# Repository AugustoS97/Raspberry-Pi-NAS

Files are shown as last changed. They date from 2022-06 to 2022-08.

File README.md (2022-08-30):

# Raspberry Pi NAS Software

NAS (Network Attached Storage) basado en Rapsberry Pi con Open Media Vault impreso en 3D con HDD de 3,5" de Toshiba alimentado a 12V.
Este diseño pretende reaprovechar los Discos Duros Externos de 3,5" USB para ser usados como NAS en una carcasa que integra todo lo necesario.
Incorpora LEDs indicador de estado (LED verde) y de encendido (LED rojo), así como OLED para identificar la dirección IP, el espacio libre y los datos de consumo de RAM y CPU.

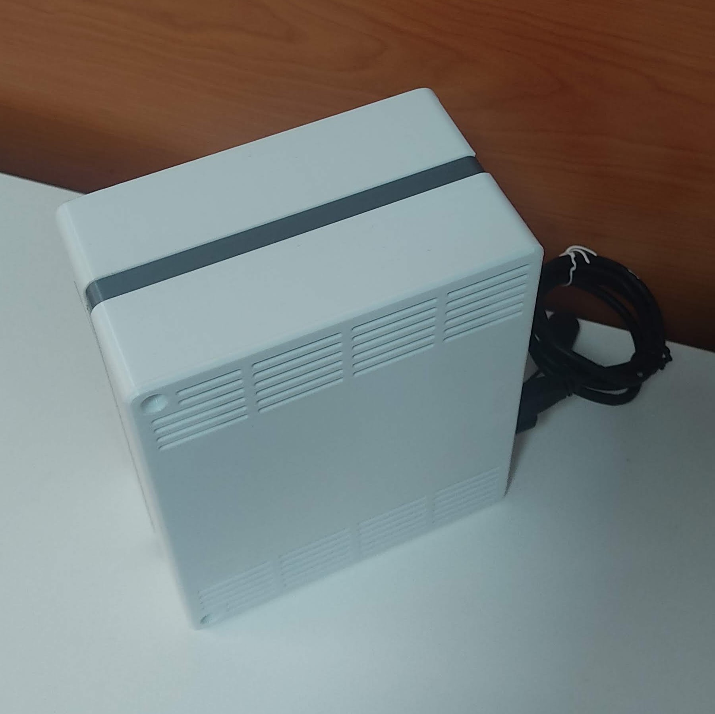
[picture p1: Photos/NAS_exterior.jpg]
NAS_exterior


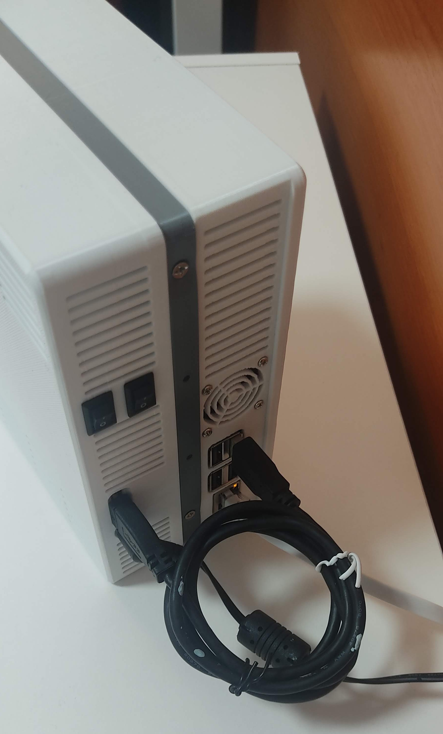
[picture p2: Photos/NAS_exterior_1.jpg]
NAS exterior 2


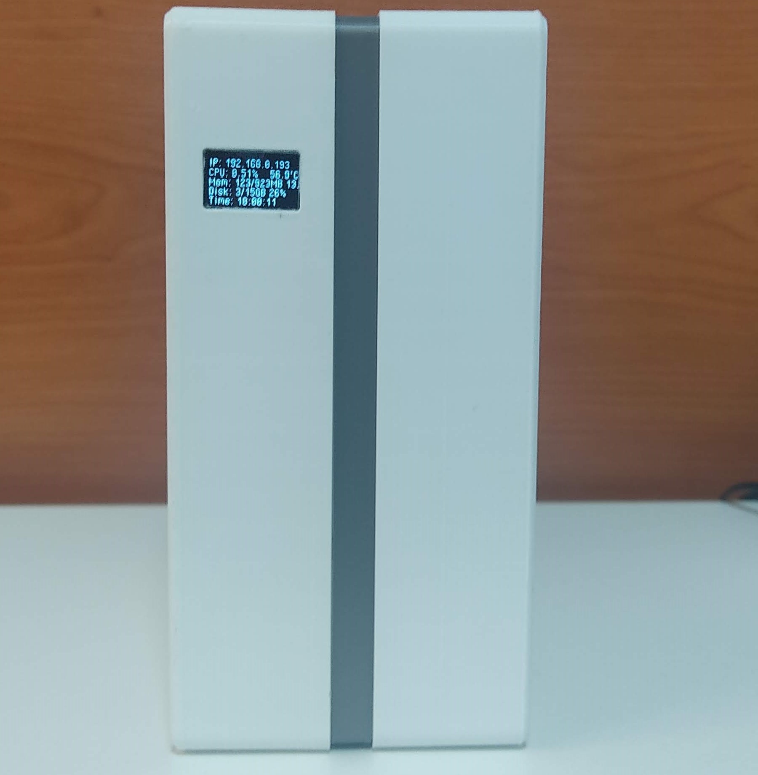
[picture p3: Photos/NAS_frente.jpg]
NAS frontal


## Lista de Materiales (BOM)

Para montar este sistema se precisa de lo siguiente:

### Elementos mecánicos

- 4 tornillos M3x15
- 12 tuercas M3.
- 10 tornillos M3x6 (para interior)
- 4 tornillos M2.5x6 (para RPi)
- 8 tornillos M3x10
- 2 tornillos M4x15
- 2 insertos M4
- Piezas impresas en PLA. Puedes localizarse en la carpeta 3D Model o en [Thingiverse](https://www.thingiverse.com/thing:5462342)
- Metacrilato de 3mm cortado para "cristal" de OLED.

### Electrónica

- Raspberry 3B+.
- Ventilador para Rapsberry Pi.
- Disco Duro 3,5" Toshiba o similar con placa de alimentación a 12V
- 2 Interruptores 8x15mm
- LED rojo
- LED amarillo
- 2 Resistencias 220 Ohm
- Regulador DC/DC StepDown MP2307 o LM2596
- Fusible 2A (Opcional para proteger alimentación de Raspberry)
- Placa para control del ventilador [PWM](https://github.com/AugustoS97/RPi-accessories/tree/main/PWM-TRANSISTOR-PCB) de diseño propio (opcional). En caso de querer controlar mediante PWM es necesario un transistor 2N2222, un diodo 1N4007 y una Resistencia de 1KOhm.
- Puede sustituirse la integración de los LEDs de estado, el fusible, el DC/DC y la placa para control PWM, empleando una [placa de expansión para RPi de diseño propio](https://github.com/AugustoS97/RPi-accessories/tree/main/LED-RPi-PCB).

### Esquema para el control PWM del ventilador

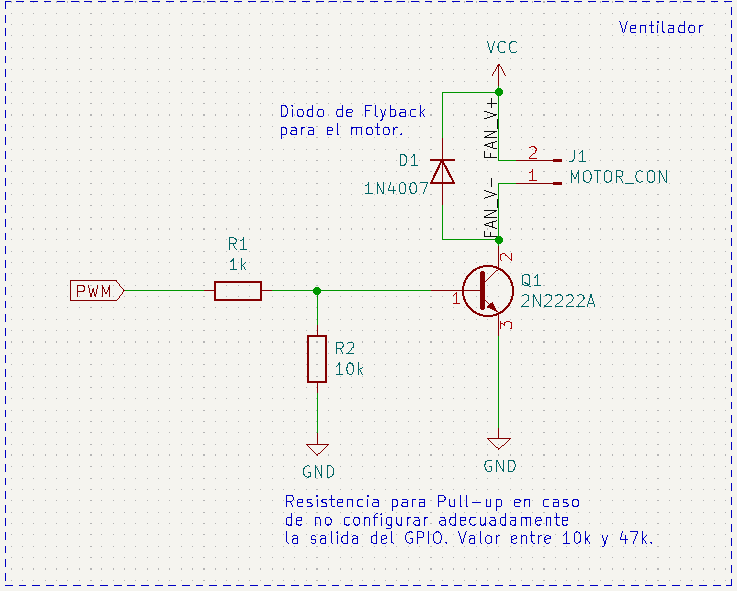
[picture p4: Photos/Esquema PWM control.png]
Esquema de control PWM


### Esquema para la Placa de expansión para RPi

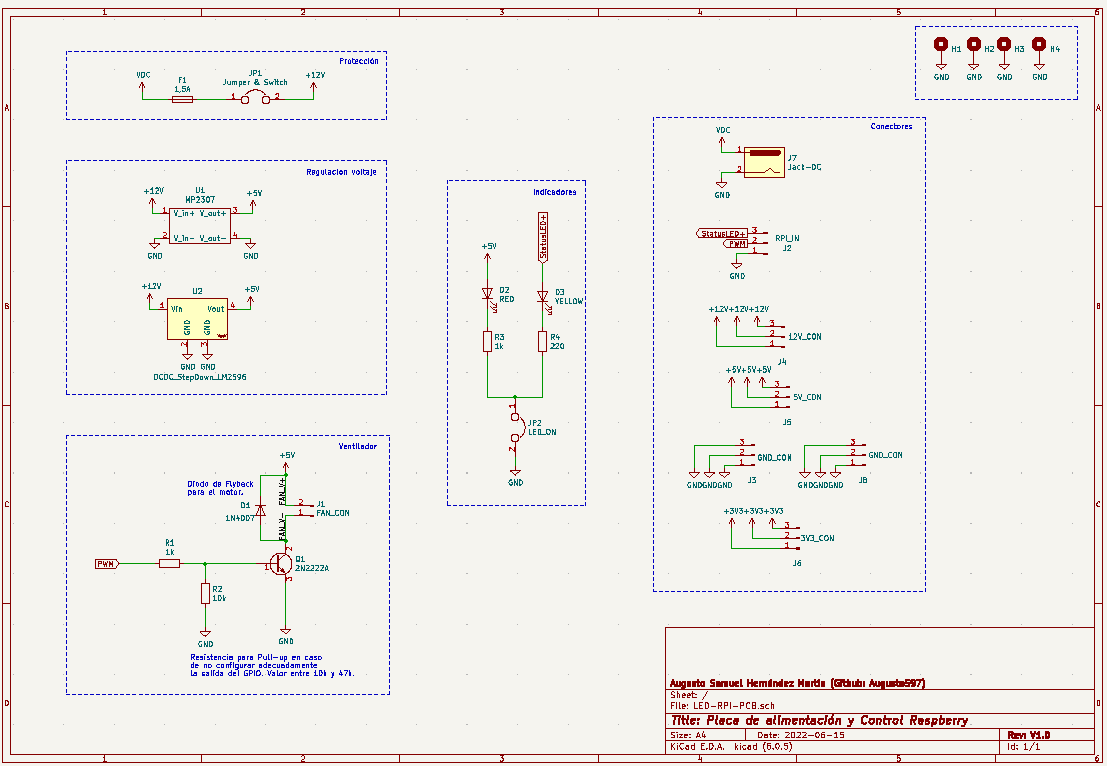
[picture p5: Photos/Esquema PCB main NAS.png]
Esquema placa RPi


## Instalar Open Media Vault

    $ sudo wget -O - https://github.com/OpenMediaVault-Plugin-Developers/installScript/raw/master/install | sudo bash $

## OLED STATISTIC

Servicio del sistema que lanza un script en python para mostar en un display OLED LCD los siguientes datos:

- Direccion IP
- Ocupacion del disco principal
- Consumo de RAM
- Temperatura
- Ocupacion del disco externo (en caso de emplearse como NAS).

## Requerimientos para el uso del Display OLED I2C

- Python3:
  
    $ sudo apt-get install python3-pip

	$ sudo pip3 install --upgrade setuptools

- Raspi blinka:
  
	$ wget https://raw.githubusercontent.com/adafruit/Raspberry-Pi-Installer-Scripts/master/raspi-blinka.py

	$ sudo python3 raspi-blinka.py

- Adafruit python shell:
  
	$ sudo pip3 install --upgrade adafruit-python-shell

- Adafruit SSD1306: 
  
	$ pip3 install adafruit-circuitpython-ssd1306

- Python PIL:
  
	$ sudo apt-get install python3-pil

## Carpeta con el contenido a copiar dentro de /home/pi

- Debe copiarse la carpeta shutdwon-monitor para permitir apagar meidante el boton conectado al GPIO-17 (pin BCM número 11).
- Debe copiarse la carpeta oled-statistic para ejecutar el script que muestra de forma continua la info en pantalla.

## Configuracion con Cron

- Abrir el configurador de cron con $ crontab -e $
- Escribir la configuracion con encendido retardado y volcado a un fichero de log: 

    $ @reboot sleep 2; /usr/bin/python3 /home/pi/oled-statistic/oled-statistic.py >> /home/pi/oled-statistic/oled-statistic.log

    $ @reboot sleep 10; /usr/bin/python3 /home/pi/shutdown-monitor/shutdown-monitor.py >> /home/pi/shutdown-monitor/shutdown-monitor.log
- Asegurarse de dar permiso de ejecucion a ambos scripts con 
    $ chmod 777 nombre.py

## Pines ocupados 

- Ventilador: GPIO 12 (PWM 3.3V). Se configura en el /boot/config.txt como 
  
    $ dtoverlay=gpio-fan,gpiopin=12,temp=60000
- LED Amarillo (Estatus LED): GPIO26. Se configura en el /boot/config.txt como 
  
    $ dtparam=act_led_gpio=26
- LED Rojo (Encendido LED): GPIO19

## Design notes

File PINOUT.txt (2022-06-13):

- Ventilador: GPIO 12 (PWM 3.3V)
- LED Amarillo (Estatus LED): GPIO26
- LED Rojo (Encendido LED): GPIO19
- Interruptor de encendido/apagado: GPIO3 y GND

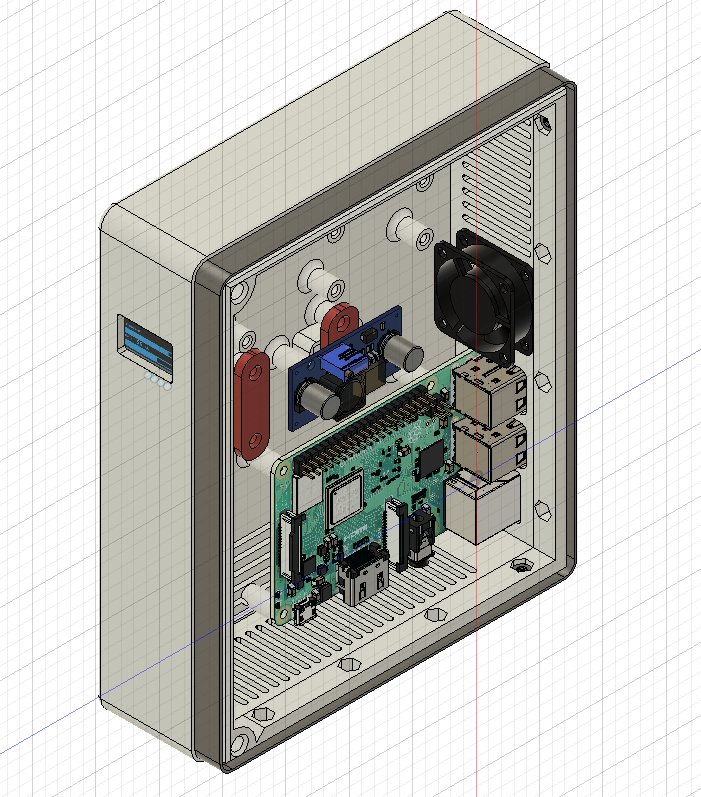
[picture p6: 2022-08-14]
3D Model/RENDER/Captura_2.png

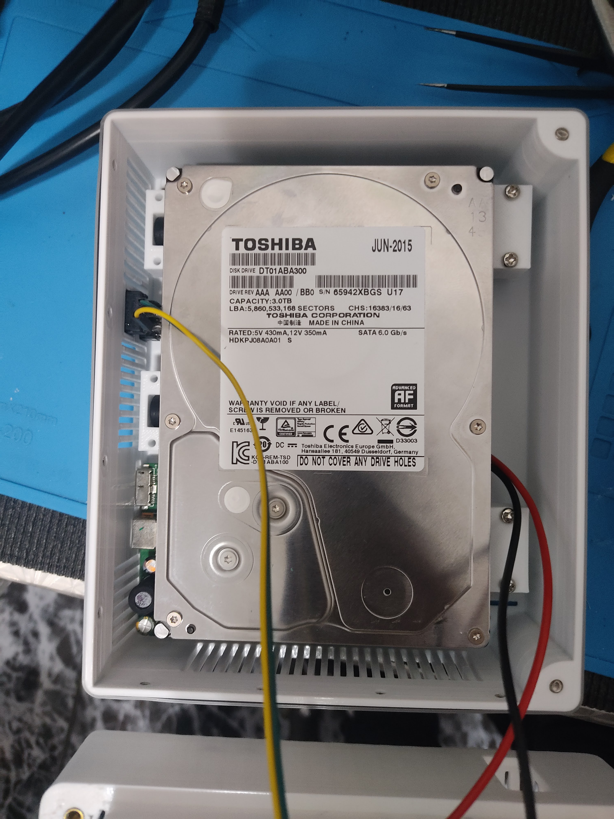
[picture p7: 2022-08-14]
Photos/NAS_HDD.jpg

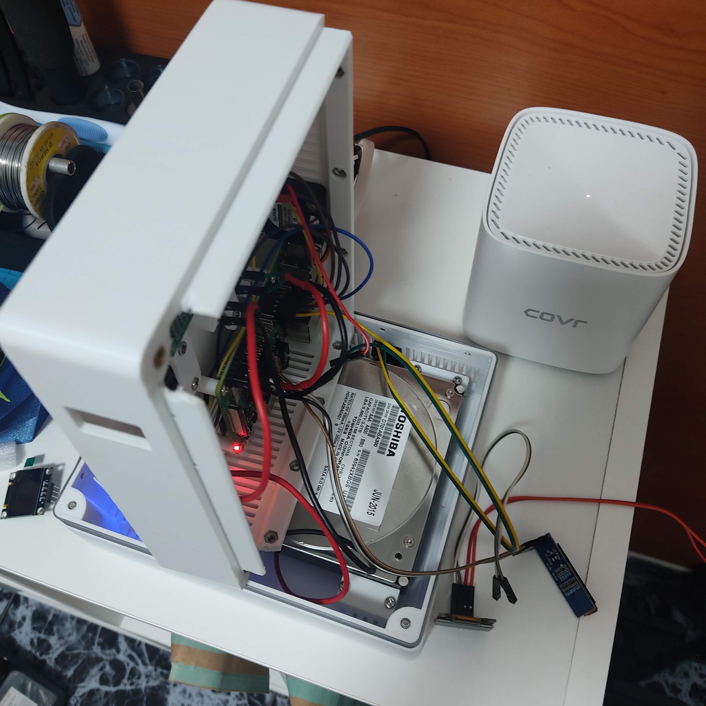
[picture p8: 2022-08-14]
Photos/NAS_interior_1.jpg

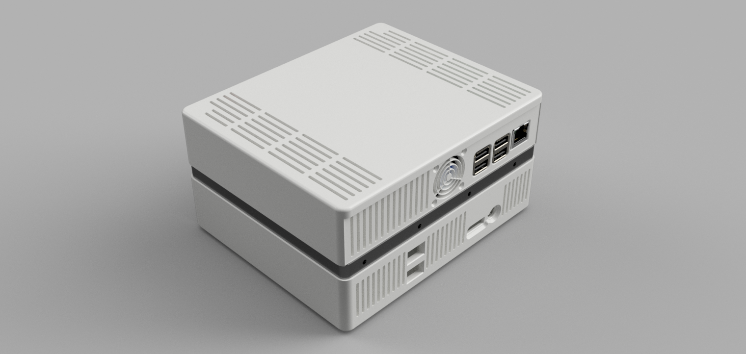
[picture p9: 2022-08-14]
3D Model/RENDER/NAS Servidor con OLED conectores.png

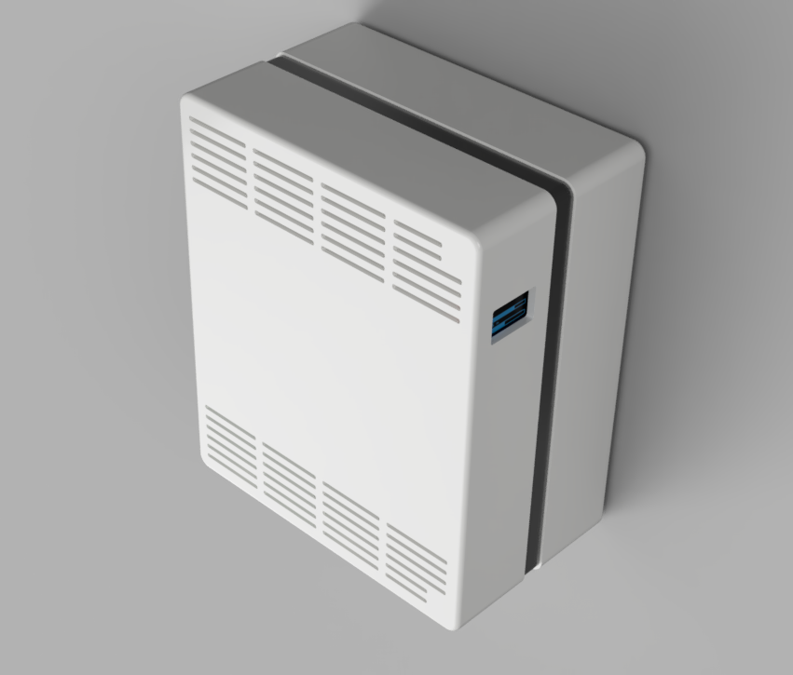
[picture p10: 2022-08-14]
3D Model/RENDER/NAS_Servidor_con_OLED_2022-Apr-21_08-00-08PM-000_CustomizedView2744614946_png.png

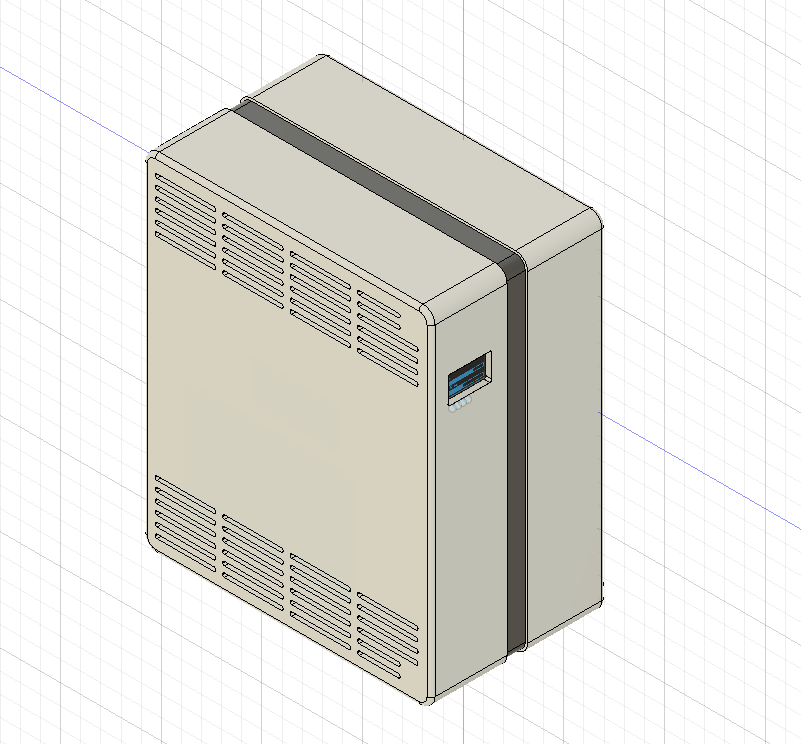
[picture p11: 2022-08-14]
3D Model/RENDER/Captura_1.png

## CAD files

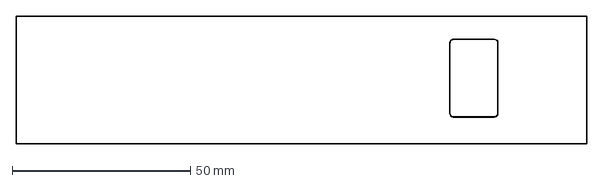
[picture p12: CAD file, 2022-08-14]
3D Model/DXF/Metacrilato 3mm pantalla OLED.dxf
160.0 x 35.8 mm

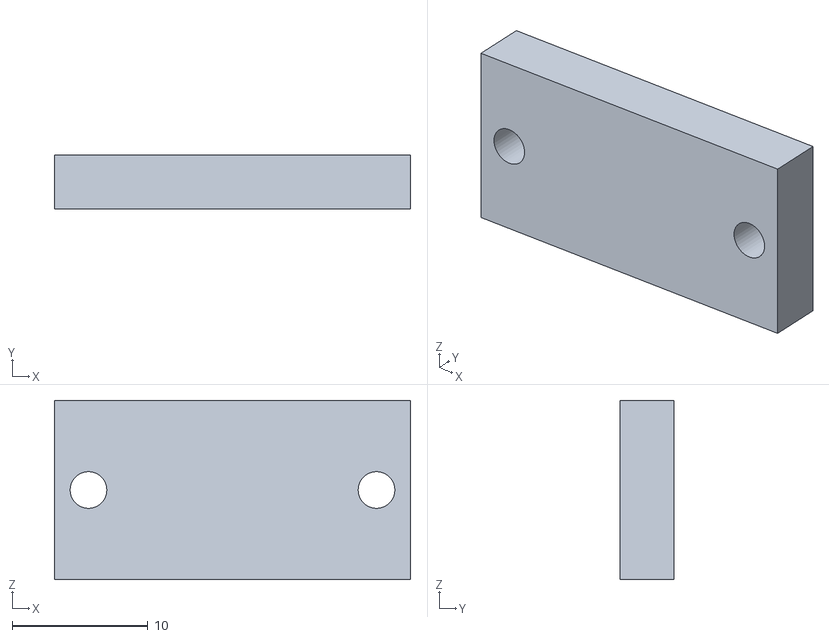
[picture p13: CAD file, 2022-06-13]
3D Model/STL/Soporte-HDD-Opuesto x2.stl
26.2 x 4.00 x 13.2

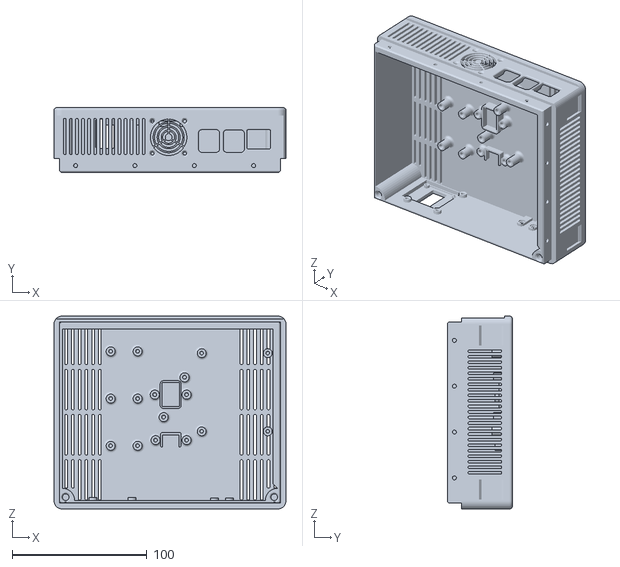
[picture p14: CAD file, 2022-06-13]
3D Model/STL/TapaDrcha.stl
172.0 x 48.0 x 143.0

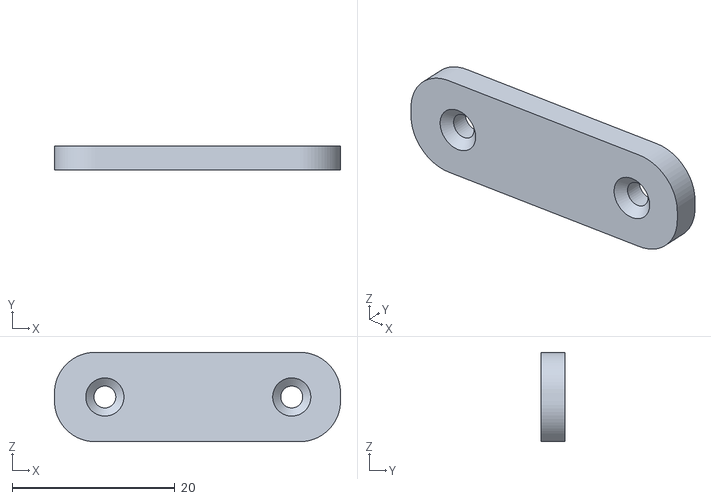
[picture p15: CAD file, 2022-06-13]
3D Model/STL/Soporte Fusible Mini.stl
35.2 x 3.00 x 11.0

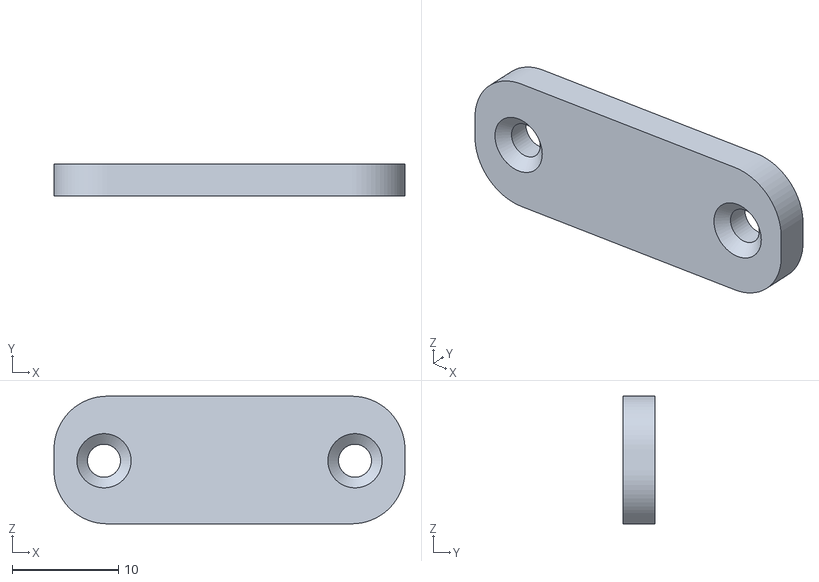
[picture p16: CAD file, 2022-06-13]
3D Model/STL/Soporte MP2307.stl
33.0 x 3.00 x 12.0

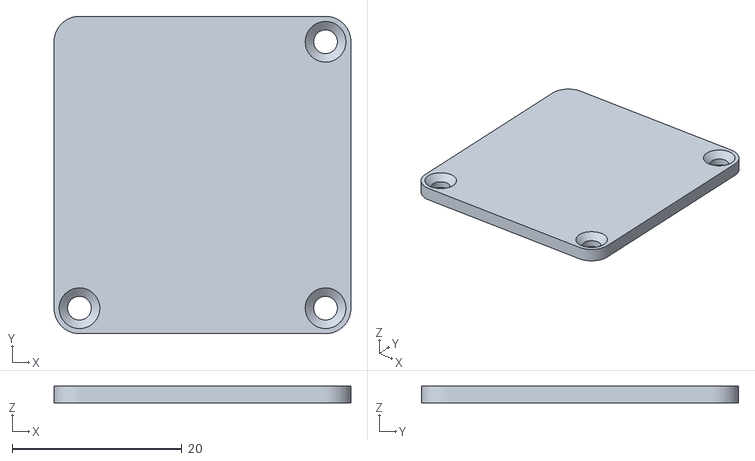
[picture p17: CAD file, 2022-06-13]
3D Model/STL/Soporte OLED.stl
35.0 x 37.4 x 2.00

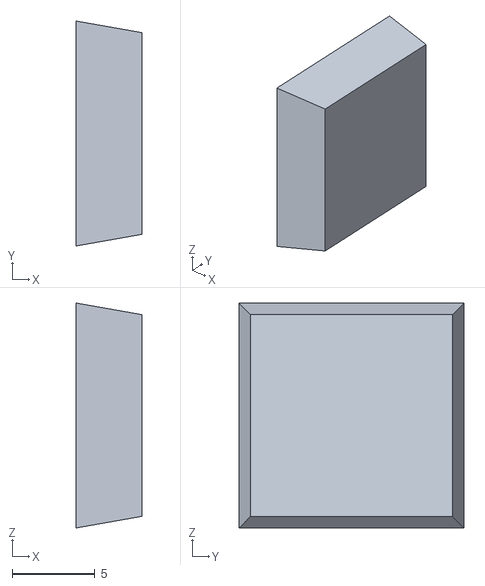
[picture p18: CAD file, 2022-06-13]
3D Model/STL/Taco Basex4.stl
4.00 x 13.6 x 13.6

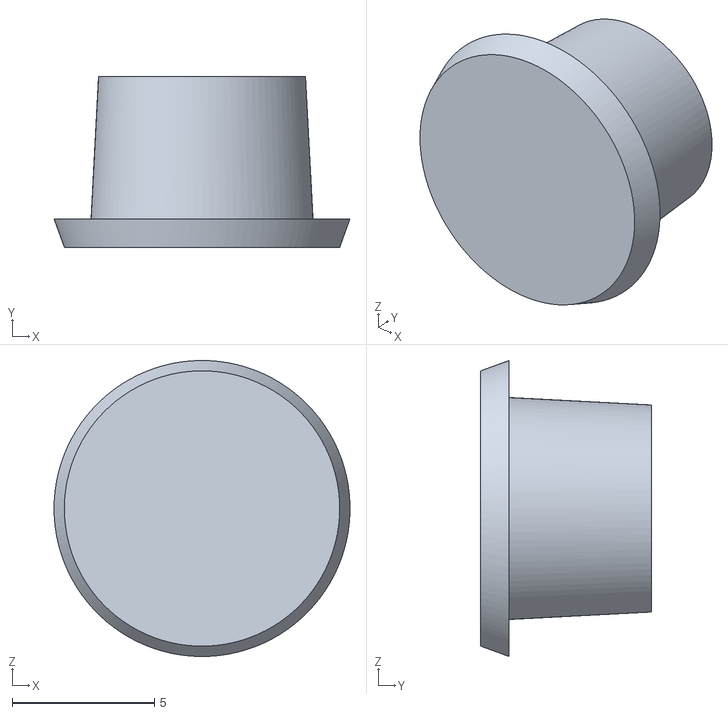
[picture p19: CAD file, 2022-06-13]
3D Model/STL/Tapon tornillos x2.stl
10.4 x 6.00 x 10.4

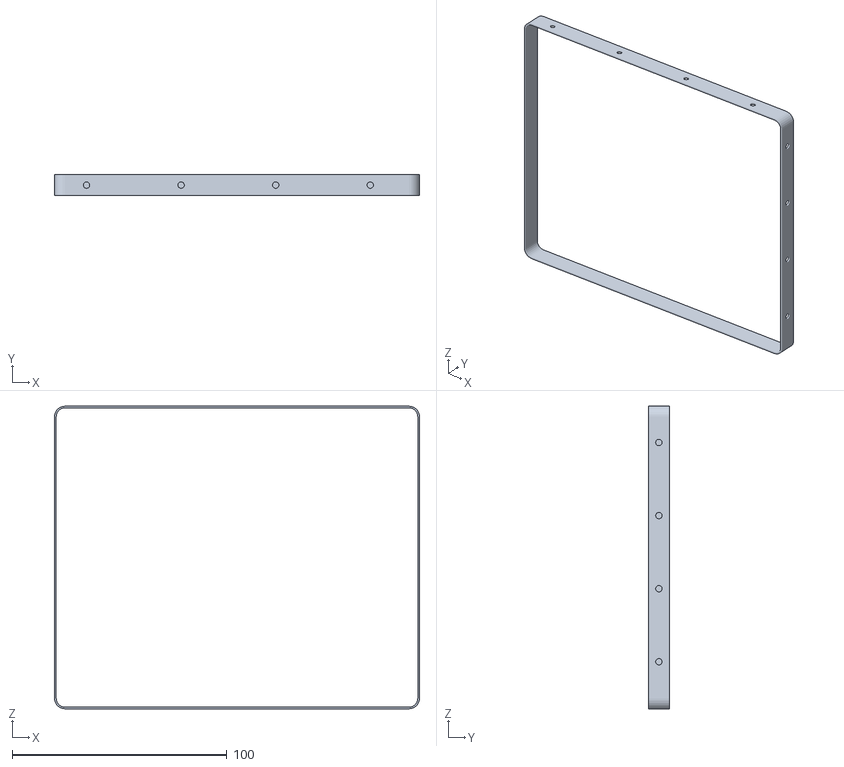
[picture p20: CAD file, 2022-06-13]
3D Model/STL/Aro decorativo.stl
169.8 x 9.90 x 140.8

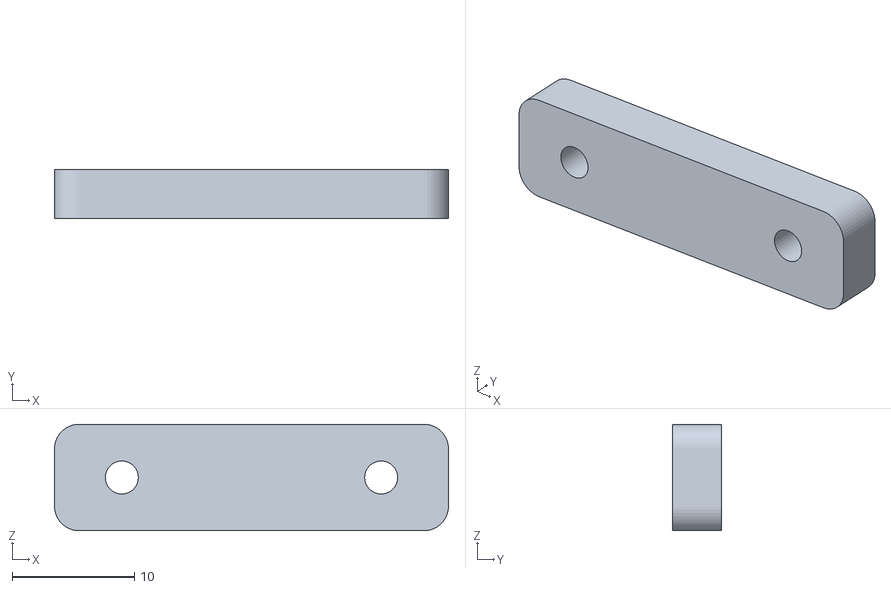
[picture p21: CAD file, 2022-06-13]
3D Model/STL/Soporte-HDD x 2.stl
32.2 x 4.00 x 8.70

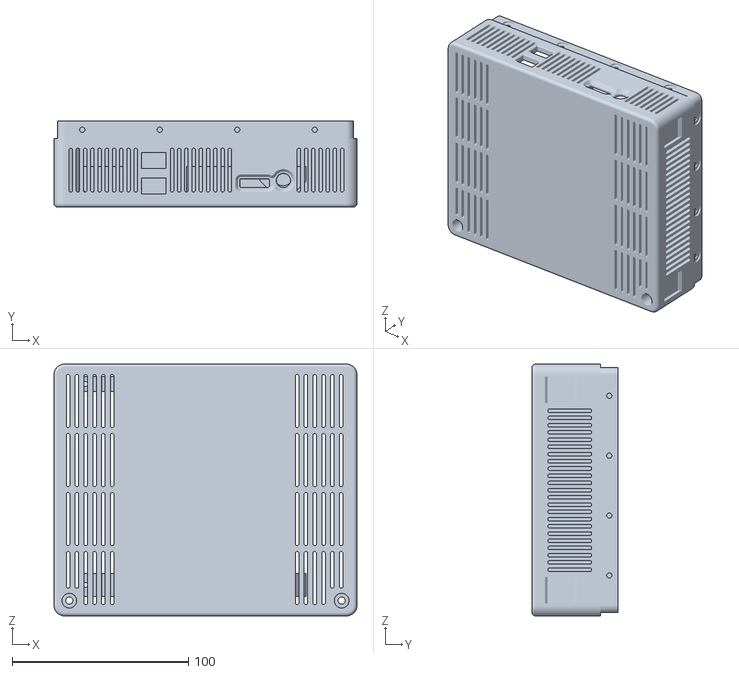
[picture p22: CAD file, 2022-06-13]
3D Model/STL/TapaIzda.stl
172.0 x 48.9 x 143.0

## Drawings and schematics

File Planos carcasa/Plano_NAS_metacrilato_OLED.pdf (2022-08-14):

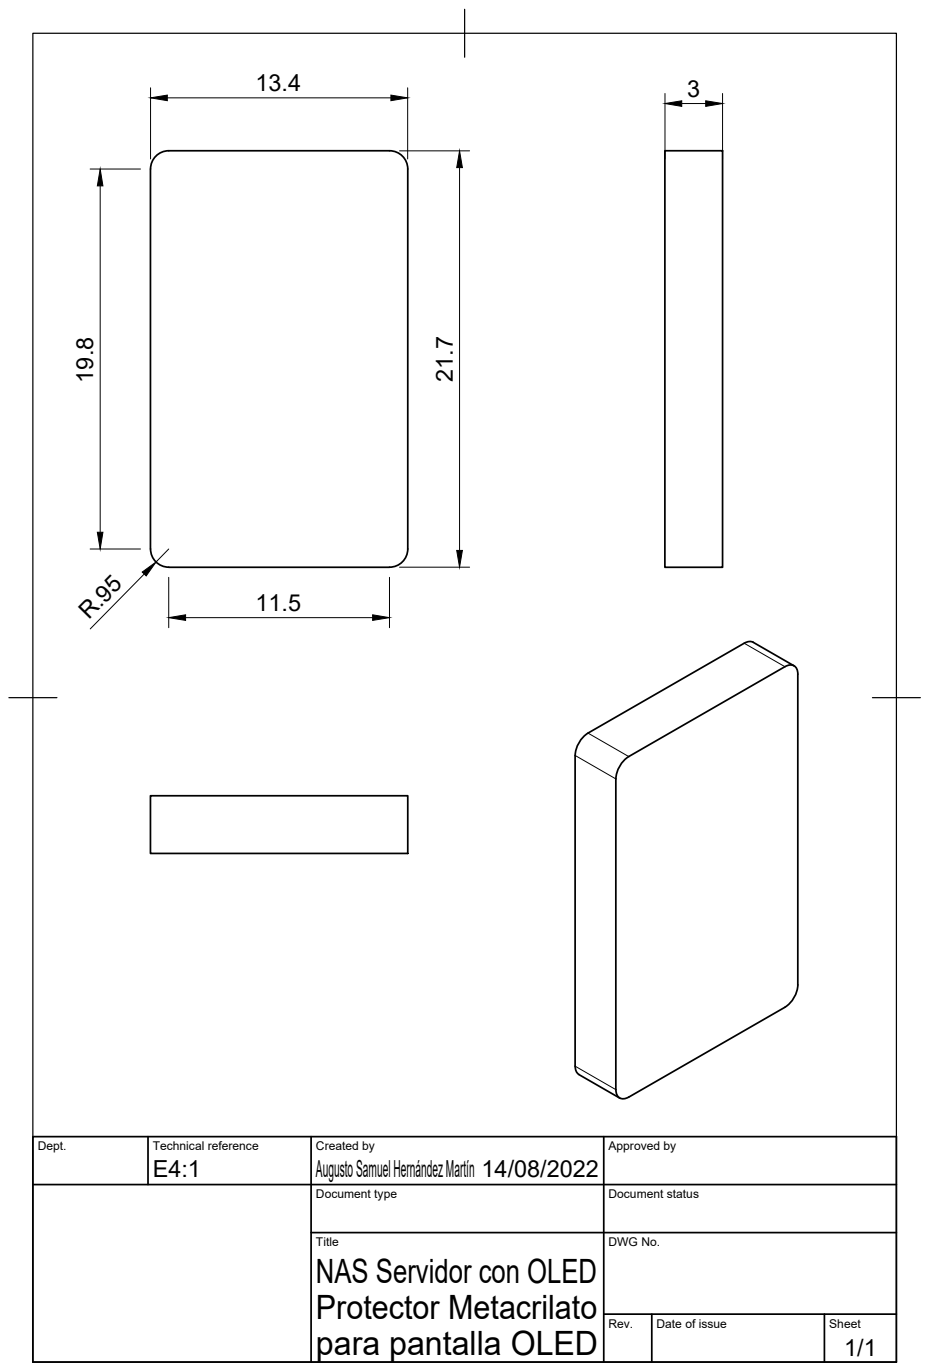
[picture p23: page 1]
Augusto Samuel Hernández Martín 21.7

Dept. | Technical reference | Created by 14/08/2022 | Approved by

Document type | Document status

Title NAS Servidor con OLED Protector Metacrilato para pantalla OLED | DWG No.

Rev. | Date of issue | Sheet 1/1

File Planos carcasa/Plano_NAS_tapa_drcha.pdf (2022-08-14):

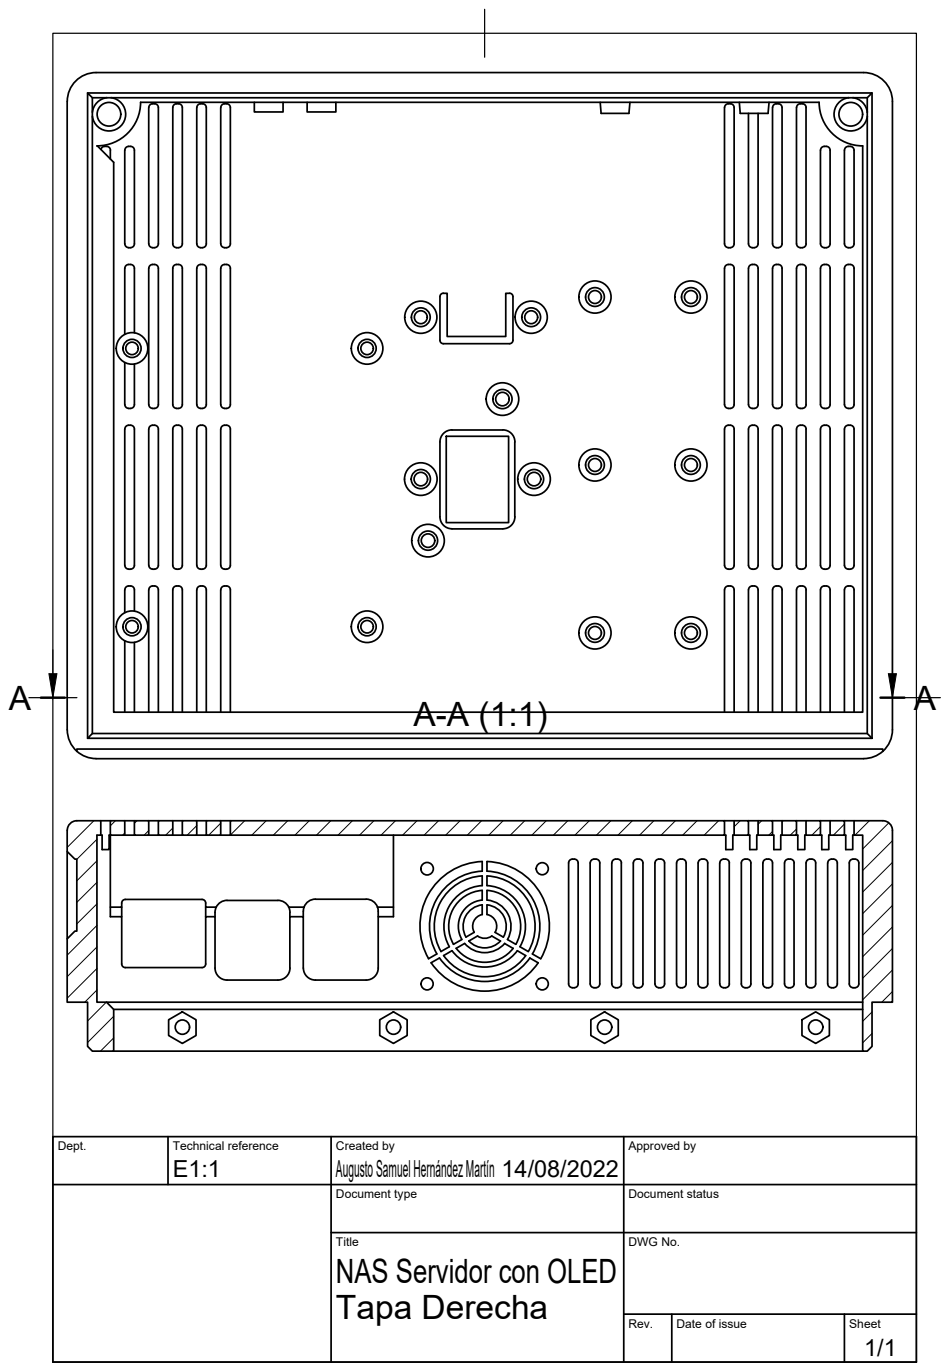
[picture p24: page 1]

Dept. | Technical reference E1:1 | Created by Augusto Samuel Hernández Martín 14/08/2022 | Approved by

Document type | Document status

Title NAS Servidor con OLED Tapa Derecha | DWG No.

Rev. | Date of issue | Sheet 1/1

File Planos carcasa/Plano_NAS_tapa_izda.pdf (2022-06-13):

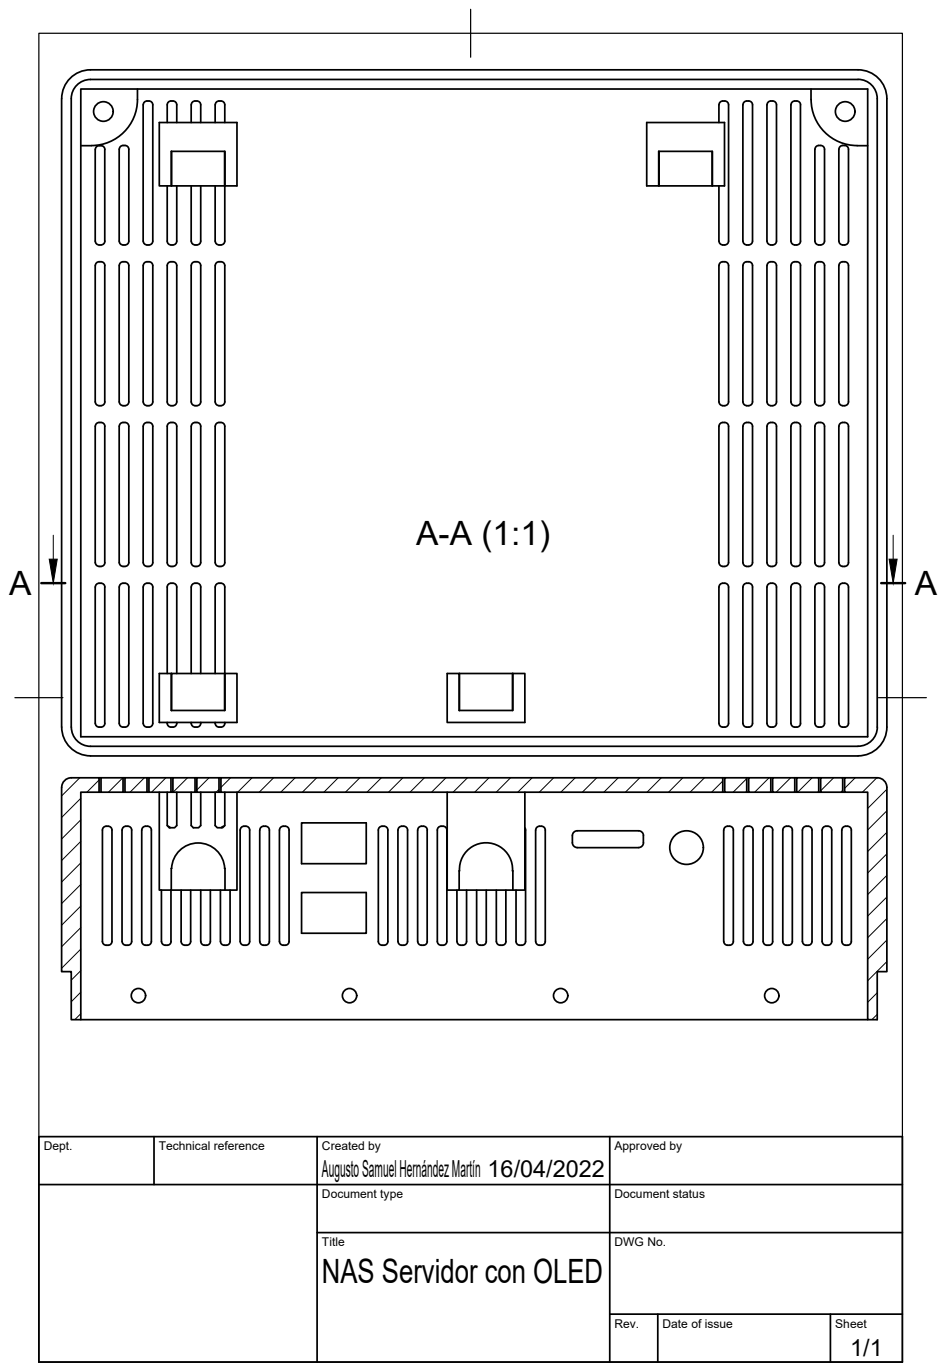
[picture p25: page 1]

Dept. | Technical reference | Created by Augusto Samuel Hernández Martín 16/04/2022 | Approved by

Document type | Document status

Title NAS Servidor con OLED | DWG No.

Rev. | Date of issue | Sheet 1/1

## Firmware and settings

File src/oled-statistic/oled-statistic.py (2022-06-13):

# Based on: Michael Klements
# Modified by: Augusto Samuel Hernandez Martin
# For Raspberry Pi Desktop Case with OLED Stats Display
# Base on Adafruit CircuitPython & SSD1306 Libraries
# It is run under a Systemd service that runs the code after start


import time
import board
import busio
import digitalio

from PIL import Image, ImageDraw, ImageFont
import adafruit_ssd1306

import subprocess

# Define the Reset Pin
oled_reset = digitalio.DigitalInOut(board.D4)

# Display Parameters
WIDTH = 128
HEIGHT = 64
BORDER = 10 #Por defecto 5

# Use for I2C.
i2c = board.I2C()
oled = adafruit_ssd1306.SSD1306_I2C(WIDTH, HEIGHT, i2c, addr=0x3C, reset=oled_reset)

# Clear display.
oled.fill(0)
oled.show()

# Create blank image for drawing.
# Make sure to create image with mode '1' for 1-bit color.
image = Image.new("1", (oled.width, oled.height))

# Get drawing object to draw on image.
draw = ImageDraw.Draw(image)

# Draw a white background
draw.rectangle((0, 0, oled.width, oled.height), outline=255, fill=255)

font = ImageFont.truetype('/home/pi/oled-statistic/PixelOperator.ttf', 16)
#font = ImageFont.load_default()

while True:
    # Draw a black filled box to clear the image.
    draw.rectangle((0, 0, oled.width, oled.height), outline=0, fill=0)

    # Shell scripts for system monitoring from here : https://unix.stackexchange.com/questions/119126/command-to-display-memory-usage-disk-usage-and-cpu-load
    cmd = "hostname -I | cut -d\' \' -f1"
    IP = subprocess.check_output(cmd, shell = True )
    cmd = "top -bn1 | grep load | awk '{printf \"CPU: %.2f\", $(NF-2)}'"
    CPU = subprocess.check_output(cmd, shell = True )
    cmd = "free -m | awk 'NR==2{printf \"Mem: %s/%sMB %.2f%%\", $3,$2,$3*100/$2 }'"
    MemUsage = subprocess.check_output(cmd, shell = True )
    cmd = "df -h | awk '$NF==\"/\"{printf \"Disk: %d/%dGB %s\", $3,$2,$5}'"
    #cmd = "df -h /dev/sda1 | awk '$NF==\"/\"{printf \"Disk: %d/%dGB %s\", $3,$2,$5}'"
    Disk = subprocess.check_output(cmd, shell = True )
    cmd = "vcgencmd measure_temp |cut -f 2 -d '='"
    temp = subprocess.check_output(cmd, shell = True )
    cmd = "date +%T"
    Hour = subprocess.check_output(cmd, shell = True)

    # Pi Stats Display
    draw.text((0, 0), "IP: " + str(IP,'utf-8'), font=font, fill=255)
    draw.text((0, 12), str(CPU,'utf-8') + "%", font=font, fill=255)
    draw.text((80, 12), str(temp,'utf-8') , font=font, fill=255)
    draw.text((0, 24), str(MemUsage,'utf-8'), font=font, fill=255)
    draw.text((0, 36), str(Disk,'utf-8'), font=font, fill=255)
    draw.text((0, 48), "Time: " + str(Hour,'utf-8'), font=font, fill=255)     


    # Display image
    oled.image(image)
    oled.show()
    time.sleep(0.8)

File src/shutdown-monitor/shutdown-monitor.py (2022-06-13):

#!/bin/python 
# Apagar Raspberry con un Botón en los terminales 8 y GND. El terminal 8 es el GPIO14.
import RPi.GPIO as GPIO  
import time  
import os  

GPIO.setmode(GPIO.BOARD)  
GPIO.setup(11, GPIO.IN, pull_up_down = GPIO.PUD_UP)  

def Apagar(channel):  
   os.system("sudo shutdown -h now")  

GPIO.add_event_detect(11, GPIO.FALLING, callback = Apagar, bouncetime = 2000)  

while 1:  
   time.sleep(1) 

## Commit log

2022-06-13 Primer commit
    [Aro decorativo.stl, Soporte Fusible Mini.stl, Soporte MP2307.stl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]
2022-06-13 Añadidos los scripts para mostrar info en pantalla y apagar NAS con botón.
2022-08-14 Añadidos los ultimos ficheros para dar el proyecto por termiando en version estable
    [Metacrilato 3mm pantalla OLED.dxf, Taco Basex4.stl]
2022-08-30 Modificado el README.
